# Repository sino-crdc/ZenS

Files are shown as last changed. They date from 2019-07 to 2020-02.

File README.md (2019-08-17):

# ZenS

Multi-function bracelet terminal based on gesture recognition.

手势识别握式手环——多功能终端接口

---
### 目录
- .idea: CLion的一些配置文件以及VCS的配置
- Bracelet Main: 手环主体程序
- Gesture_Detect_Debug: 手势识别的调试程序
- IRrecord: 红外编码收集器
- Model_Physics: 物理模型
- Model_UML: UML模型
- Papers: 项目参考的论文
- Schematic: 原理图(PCB\\电路图\\Datasheet)
- Sotuion: 项目的方案性文件
- CMakeLists.txt: CMakeg构建脚本(暂时没用)
- _config.yml: 项目官网配置

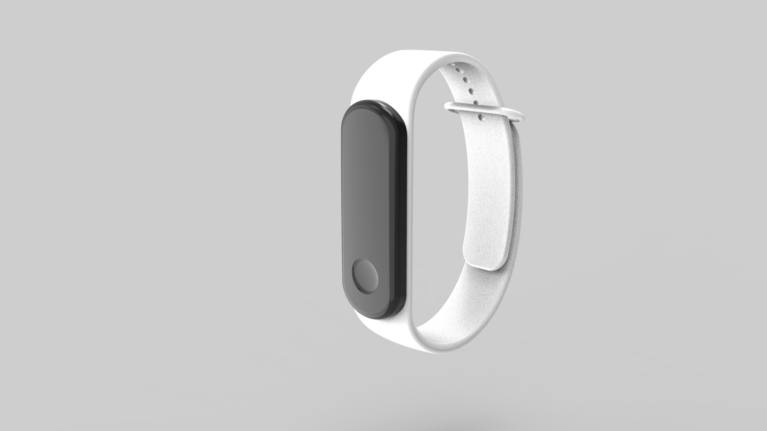
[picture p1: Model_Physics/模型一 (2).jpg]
Notion Image0

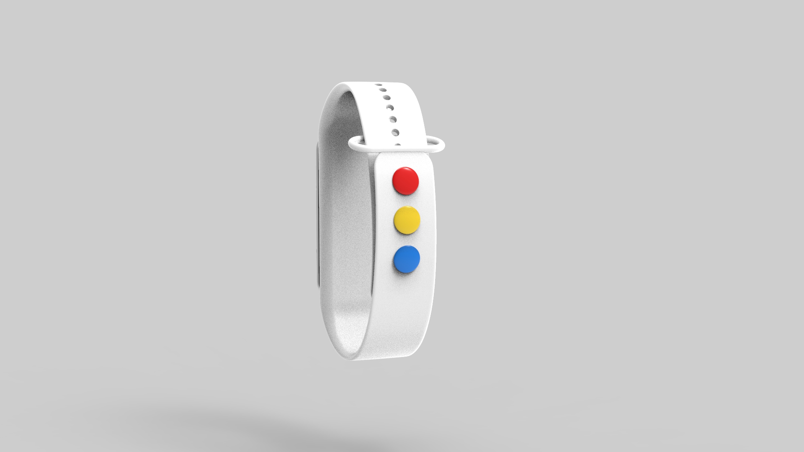
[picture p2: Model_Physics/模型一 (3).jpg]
Notion Image1


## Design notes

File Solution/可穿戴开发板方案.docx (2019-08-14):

# 可穿戴开发板方案

## 需要解决的问题

动态内存(SRAM)问题，时钟问题，大小问题，舒适度问题

## 开发板选择

1. Arduino LilyPad Simple

- 规格：工作电压：3.3V DC 核心控制器：Atmega328V-20PU 外形尺寸:外径50mm,PCB厚度4mm 接口模式；PH2.0
- 具体方案：将LilyPad Simple的PCB原理图修改，取掉不必要的引脚，减小接线片和板空余，印制在硬板或者柔性PCB板上；换芯片为ATmega2560芯片或者Atmel SAM3X8E芯片，芯片引脚与PCB引脚对应连接，剩余芯片引脚不管。芯片兼容性由软件负责人王泽坤、段飞宇和硬件负责人高崇涵、赵宇轩共同完成。

2. Arduino Mega Pro

· 规格：厚度 4mm

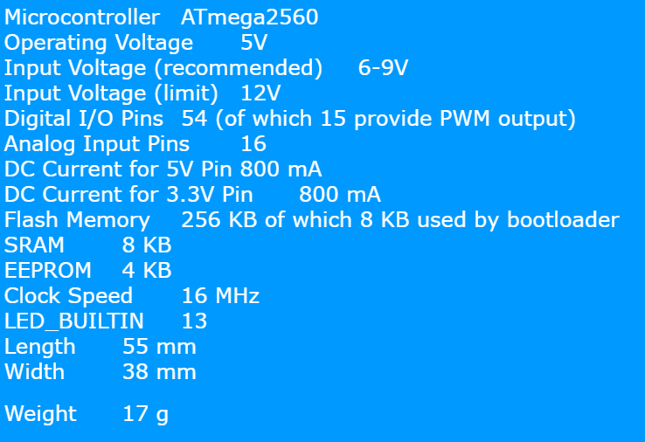
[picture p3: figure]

- 具体方案：可以原封不动，无需修改；也可以修改，将其PCB图去掉不需要的引脚，减小接线片和板材大小，印制在硬的或者柔性PCB板上；更进一步的修改：将芯片ATmega2560换成Atmel SAM3X8E

3. Arduino TinyLily或者TinyDuino

- · 规格：
- TinyDuino: Arduino和LilyPad兼容，可以使用专门的TinyShield扩展板扩展功能，可选的电池托盘（CR16120-CR1632），0.1”间隔的接口用来扩展外部电源，小尺寸和重量（比米国25分币更小），20个IO口（14个数字和6个模拟）-支持所有的Arduino接口！，预置Arduino Bootloader，已经准备好相当数量的堆砌器件
- TinyPad : Arduino LilyPad兼容,可以洗,可以缝超小尺寸（14毫米直径，高度2.8毫米）AtMel328P的cpu 8个IO口，4模拟，4数字 预置Arduino Bootloader USB扩展头
- · 不需要更改PCB，但可能需要印制空板(即不带芯片)
- 芯片均为ATmega328P芯片, 可以牺牲一部分软件稳定性和效率，将全局变量存在Flash当中避免芯片的更换
- · 如果不想牺牲程序效率，那么更换芯片为ATmega2560或者Atmel SAM3X8E
- · 或者仍然采用ATmega328P芯片，但是要多个开发板(或者叫开发小片片)分布式编程，这可能对编码要求比较高，并且芯片的时钟数可能仍然是限制。

4. 改用Nano\Micro\Mini\Leonardo Mini等，均需要换芯片，可改PCB

5. 其他开源开发板Flora\Gemma\Trinket等，均需要换芯片，可改PCB

6. 改用STM32或者ESP8266

7. 改用MCS51单片机

## 动态内存(SRAM)问题

造成内存问题主要是Device中的三个数组，总共占用空间峰值为300KB（最多命令数KB）

1. 减少最多命令数量到50，但是仍然需要扩充动态内存到50KB以上(50-70)

2. 更换芯片，ATmega2560仅有8K还是不够大，应该换成Atmel SAM3X8E

~~3.~~ ~~只更换A~~~~Tmega2560~~~~中的S~~~~RAM~~

4. 将三个数组存储在ROM中(ROM最大空间为300KB), 但是只读

5. 外接RAM

6. 牺牲运行速度，删除三个数组，或者将其换为文件存在SD卡中

7. 将三个数组换为文件存在SD卡中，并提供相邻指令加载算法，即发送B命令编码时候，加载A和C的编码并存在小数组中(一元算法)，根据转动角速度阈值，给出算法的元数(即所加载的相邻指令的数量)

7. 分布式开发板

## 时钟问题

1. 更改芯片内部晶振或更改芯片

2. 换外部时钟

3. 更换单片机开发板

## 大小问题

1. 更改可穿戴开发板方案

2. 更改模式，采用手环+手机或者手环+外部固定单片机或者手环+外部动态单片机或者手环+计算机的模式

## 舒适度问题

1. 更改外壳材料

2. 采用柔性PCB

3. 人体工学

*焊接：更换芯片时候会用到SMT表面组装技术

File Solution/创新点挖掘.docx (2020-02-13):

# 创新点挖掘

定位：终端接口API → 二次开发 → 新型交互方式 → 多样应用场景

1. VR/AR交互

2. 汽车交互

3. PPT交互

4. 设备交互

5. 家居交互

6. 聋哑人群智能家居方式

7. 游戏终端

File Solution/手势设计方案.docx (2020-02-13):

# 手势设计方案

手势通过两种途径与操作关联：运动关联以及图形关联

1. 用户通过电脑设置：需SD卡插入电脑
A. SD卡文件编辑或者桌面应用端，用户通过输入手势表达式或者角度表达式为不同设备不同操作设定手势
B. 在桌面应用端，用户为不同的设备不同的操作选择系统已经提供的手势。
C. 在桌面应用端，用户开启电脑前置摄像头，通过计算机视觉识别用户所作手势，对所选设备和操作设定手势
D. 针对手势识别的train_class方案，结合C
2. 用户通过手环设置：
A. （需要电脑，需SD卡插入电脑，需红外接收器插入电脑）用户用手环做出手势，将手势信息(表达式)通过红外发射到接收器，接收器连接电脑并将数据传到桌面应用端，从而结合方案1设定手势

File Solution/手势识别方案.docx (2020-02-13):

# 手势识别方案

1. 三维霍尔效应传感器
2. 加速度传感器/陀螺仪/角速度计
3. 三个位移传感器
4. 三个测距传感器
5. 三维位置传感器
6. PSD位置传感器

最终确定为方案2，并作如下设置：

定性手势是指不含数值操控的命令手势，比如打开空调、打开空调摆风等。

定量手势是指数值操控的命令手势，比如调整电视音量，调温等。

定量启动手势是指标识定量类型手势的手势，在定量手势之前，是半定性手势半定量手势。

两种手势的区分是：在.infos表中，定量和半定量手势的orderType的开头加一个前缀“$”

手势指令(Gest_Data)：

1. 定性：x+x-分别为x轴正向负向，y+y-为y轴，z+z-为z轴；表达式为”0+1-2+”等
2. 定量：(initial, 180+initial)->(最小值，最大值)，x轴角度，含x轴角速度测量，太大不作用。表达式数值保留一位小数，表达式为“3.8~10.6”等，在角度最大值180°上，考虑到范围超出(抖动或者积分延续)的情况，在表达式中设置18°的误差(“169.0~198.0”):在角度最小值0°上，考虑到抖动至负值的情况，在表达式中设置10°的误差.
3. 半定量：要求最终手部的姿势为胸前平端拳(手心朝下)

手势开发点：

1. 角速度的利用
2. 加速度与角度变化配合：轨迹识别初步
3. 加速度图像识别与积分(图像)识别与双积分：轨迹识别过渡
4. 加速度积分与角度的配合：轨迹识别
5. 其他手势识别方案的尝试与应用

由于JY61芯片MPU6050的固有问题，传送数据的误差较大，数据错乱难以解决，所以更换为LSM9DS0芯片上的加计陀仪。

在方案2中，细分为如下方案：
1. read_process(即读即理): 每读取一包数据立马传到手势检测函数中生成手势表达式或者角度表达式

2. read_store(即读即存)：每读取一包数据，先按照类别存到EEPROM后者SD卡中，之后在手势检测函数中生成手势表达式或者角度表达式

3. train_class(训练分类)：将所有数据读取并上传至电脑，经过与深度学习持久化模型的比对生成手势表达式或者角度表达式(甚至轨迹表达式)传回手环

4. hardport_read(硬串口读取)

定量手势使用read_process方案或者hardport_read方案

定性手势使用四种方案中的一种

定量手势选择为hardport_read方案

定性手势待定

定性手势碰到三个噪音问题，一个自由度问题，一个抓取问题

1. 低阈噪音：将阈值设低容易误读，将阈值设高手势力度要求高
2. 错轴噪音：一轴运动多轴数据
3. 眩晕噪音：多次测量后，加计识别不稳定，需要停歇
4. 轨迹自由度：目前手势轨迹限制为“六向不重复”类型
5. 蒙特卡罗抓取：数据的抓取带有时间随机性，可能在运动时，运动过快(本质是抓取过慢)导致运动时没有加速度数据被抓取，除非正好在运动的时间内抓取到数据。(导致两个问题：一个是不得不让用户重复动作以获取标准手势，另一个是不得不使用simplify函数将一个运动路径单位中抓取的多个数据输出的手势表达式项去重，手势轨迹限制为“不重复”类型)

解决办法：

1. A. 在原有程序中设高阈值，可解决部分错轴噪音。

B. 机器学习办法

2. 一次只读取一轴数据，在原有程序中，判断三轴数值变化幅度，取幅度最大者为阳性，可解决阴性轴上的低阈噪音。
3. 检测眩晕，眩晕时托起程序并显示信号
4. 突破六向限制使用机器学习方法，突破不重复限制需先解决蒙特卡罗抓取问题
5. 加快数据读取与处理(如使用read_store方法)，去掉串口信息语句

基于加计陀螺仪的手势识别方案

1. 传统方案：通过加计判断方向，通过角度判断量值
2. 全角度机器学习方案：通过角度判断轨迹和量值
3. 全数据机器学习方案：通过加速度和角度判断轨迹，通过角度判断量值

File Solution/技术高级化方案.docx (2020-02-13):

# 技术高级化方案

1. 板载机器学习：在开发板中，编写简单的机器学习代码，在手环内单机运行
2. 联网深度学习：增加WiFi模块使设备联网，远程提供深度学习服务，通过手势识别的train_class方案，实现多样的手势识别
3. 定向通信握手：不使用四个按钮对应不同设备，而是使用定向握手的办法，即对准设备，按下按钮，定向发射信号定向回传信号完成设备握手后，(任意指向)做出手势进行操作。
4. 去经验化：手环程序中很多值，比如加速度初始值阈值，角速度阈值等等都是根据肉眼观察到的数据经验地设置的。可以使用MATLAB/Simulink或者其他软件或者数学方法得出一个科学客观的值。

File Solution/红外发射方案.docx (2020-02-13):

# 红外发射方案

红外发射存在两个问题，一个是发射方向的问题，必须对准发射；另一个是发射功率的问题，必须近距离发射。考虑红外反射的话，发射方向问题可以看作为发射功率问题

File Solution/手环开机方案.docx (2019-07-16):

# 手环开关机方案

1. 脱磁方案：磁性一方面可以稳定手环在存放盒中的位置，另一方面方便无线充电，再一方面通过磁感应控制继电器开关。

缺点：需要手环内部带于磁性作用的物质。没有锁定。

优点：位置调控精准，恒定不需能源，相对简单。

2. 机械方案：放手环时通过机械传动关闭开关，拿手环时打开。通过锥形定位等力学定位。

缺点：设计复杂，容易损坏，定位不准。没有锁定。

优点：恒定不需要能源，不需额外传感器或磁器件。

3. 人体感应方案：存放盒内放置感应器，感应到人手后通过机械开/关机。

缺点：需要能源，甚至需要开发板。判断也不准。没有锁定。

优点：设计简单，对手环的要求小。

4. 盒内置推压按键方案：插入盒中的四指推动四个推压按键，通过传动开机，等待3秒后，打开锁定以便拿出手环。通过压力传感器判断放还是拿手环。

缺点：传感器众多，需要开发板。设计复杂。需要能源。容易损坏。

优点：有锁定，对手环的要求小。

*锁定：由于拿出手环后1-3秒，需要让手环处在标准姿态下(手的四指朝下，手心向后，手垂直于地面，手环的加速度为0)，以便手环中手势识别程序部分的校准工作：z轴归零和加计校准。

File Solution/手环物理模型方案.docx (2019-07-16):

# 手环物理模型方案

一、 手背全覆盖模型

针对：LilyPad Simple\Flora\Gemma

材料：中密度纤维板(MDF)或者其他硬质塑料，弹性布料

外形：手背部分整体是一个覆盖全手背的圆形，贴近手背皮肤的部分采用人体工学设计(比如不能带棱角硌手)；手心部分要足够窄小薄，可硬可软，同样要符合人体工学(比如手指按下去能方便的按住按钮，四个按钮的相互距离要适中等)。

二、 手背半覆盖模型

针对：Mega Pro\Nano\Micro\Mini\Leonardo Mini\Trinket

材料：中密度纤维板(MDF)或者其他硬质塑料，弹性布料

外形：手背部分整体是一个覆盖贴近指根部关节的那半部分手背的长条，贴近手背皮肤的部分采用人体工学设计(比如不能带棱角硌手)；手心部分要足够窄小薄，可硬可软，同样要符合人体工学(比如手指按下去能方便的按住按钮，四个按钮的相互距离要适中等)。

三、 排列块模型

针对：小块针对TinyLily\TinyDuino，大块针对Nano

材料：中密度纤维板(MDF)或者其他硬质塑料，块连接线用弹性材料

外形：手背部分类似于Myo腕带，一个块放一个元件/开发板，块间用较宽的弹性带连接(电线套细小绝缘套，盘绕嵌在里面)；手心部分使用弹性带，按钮嵌在里面或外露。

四、 夹层带模型

针对：TinyLily\TinyDuino，柔性PCB

材料：上下外层采用松紧带或其他弹性材料/皮革等，中间内层为各元件/开发板/芯片的上下再各加一薄层硬质材料以保护(增强韧性)

外形：类似绷带，手背部分覆盖半手背，手心部分更为窄小。

注：

1. “针对”详见方案文件《可穿戴开发板方案》

2. 尺寸参数：各开发板的尺寸参数在 “Model_Phsics/parameters/《可穿戴开发板方案》“中给出，未给出的需自行查找，各元件(模块)的尺寸参数长宽以图片的形式给出，厚度均为5毫米

3. 元件的位置排布可与开发板分开，也可以热熔胶粘在开发板表面，视模型和电路等而定，但不能过于拥挤混乱，也不能过于分散浪费空间。而且元件位置排布万万不能反人类，比如“四个按钮和四个发光二极管的位置不对应“。

4. 注意外壳开口或透明：红外发射管外露，发光二极管可见，充电接口(母端)外露，电源按钮外露，SD卡可外露(方便用户取出)可不外露。

5. 加计/陀螺仪/角速度计的放置：x轴手指指向，y轴垂直手指指向向大拇指方向，z轴由右手定则垂直手背面向天。即如图所示：

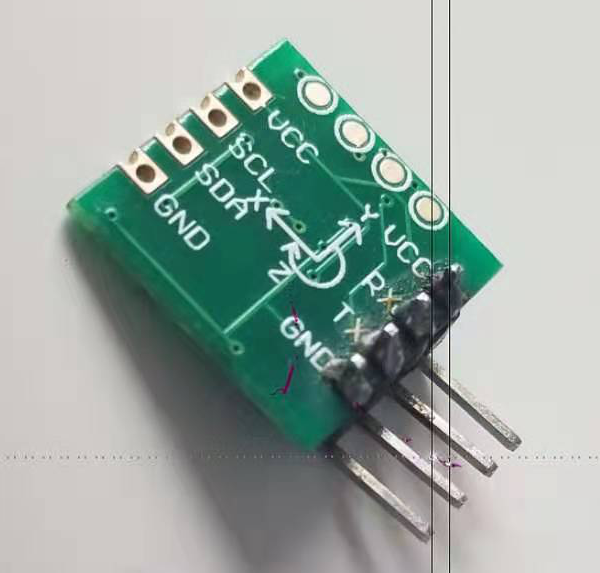
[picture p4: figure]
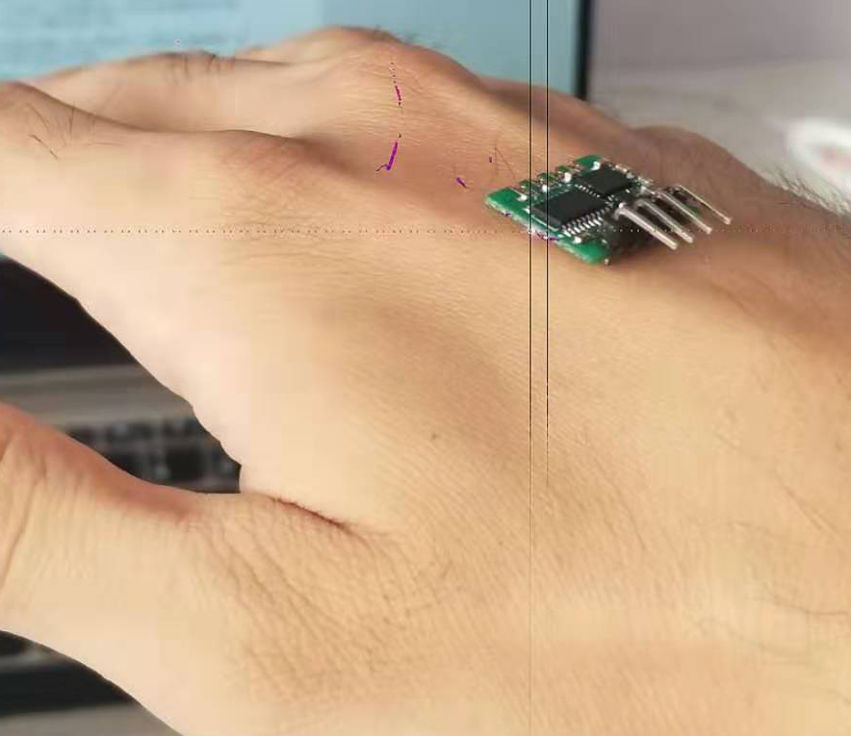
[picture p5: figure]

6. 所有模型均为右手，左手模型日后再议。

7. 从手背走向手心的部分(手侧部分)是决定模型(戴在手上的)稳固性的关键，这部分设计不能太细小窄小，也不能太肥大，要平滑过渡，必要时考虑采用松紧带或者其他弹性材料。

8. 针对STM32\ESP32\MCS51的模型可以是任意的。

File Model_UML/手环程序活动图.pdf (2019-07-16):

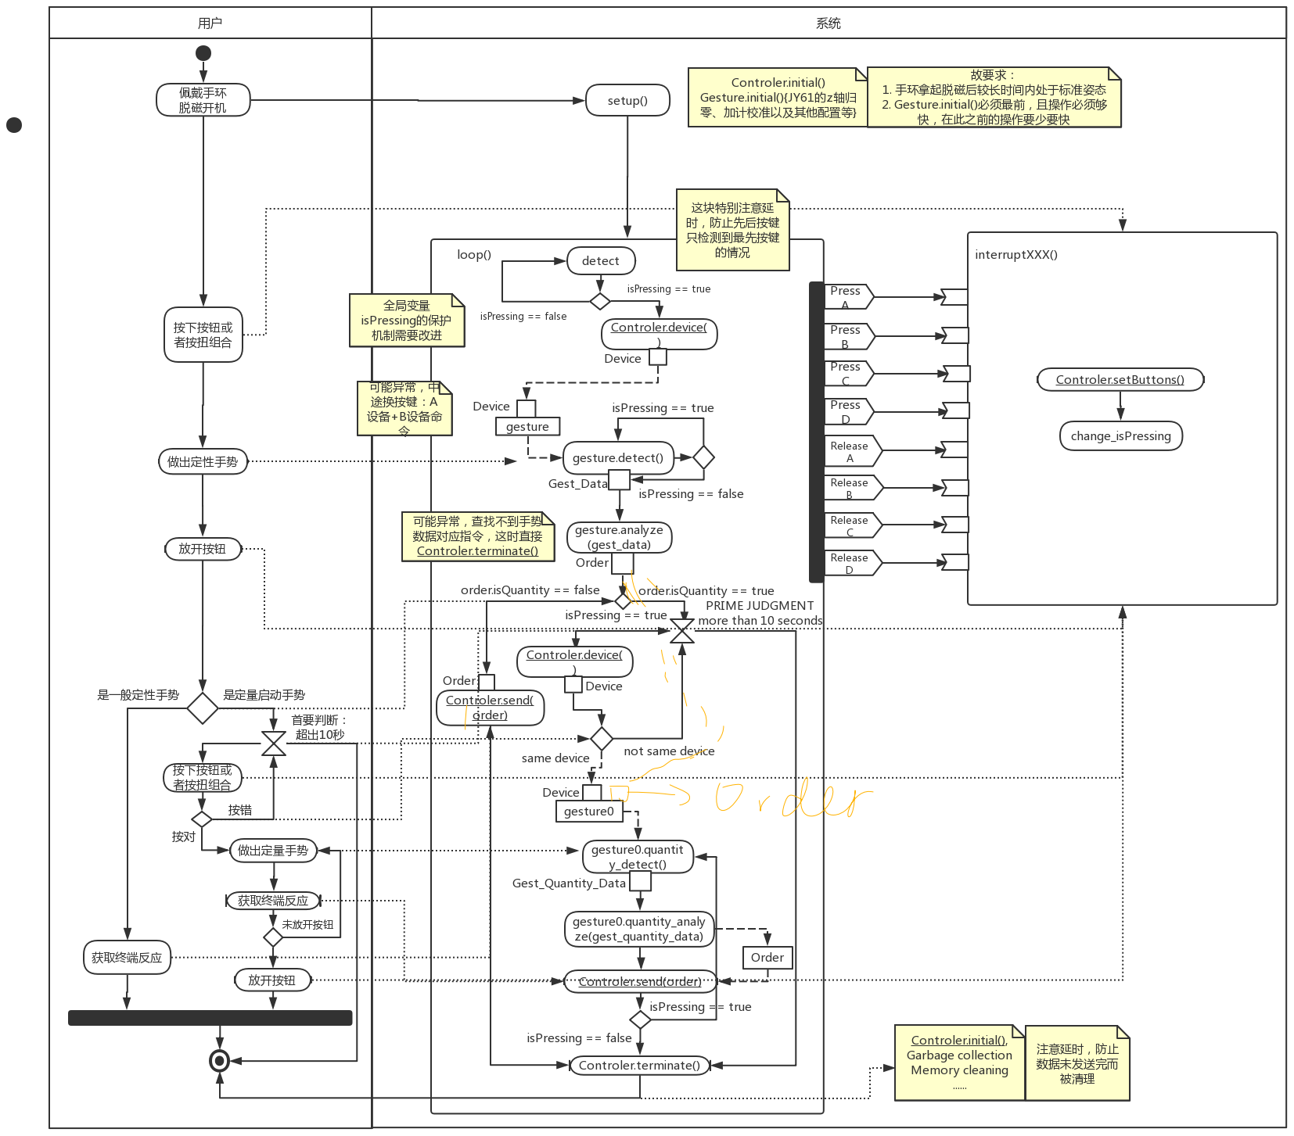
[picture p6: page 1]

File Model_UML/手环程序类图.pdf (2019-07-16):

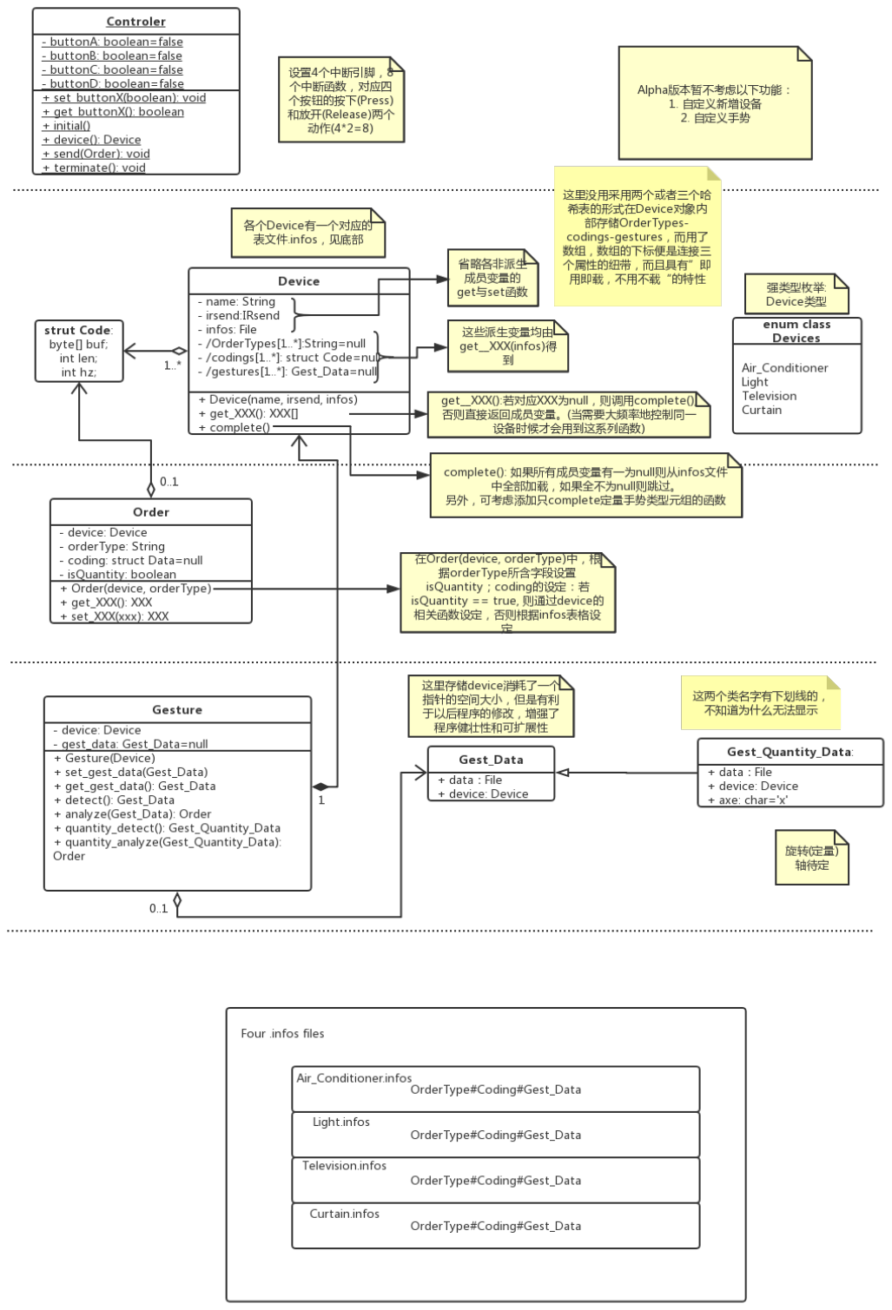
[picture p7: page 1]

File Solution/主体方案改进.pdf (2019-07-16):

# 主体方案改进

方案名称：手握式手环

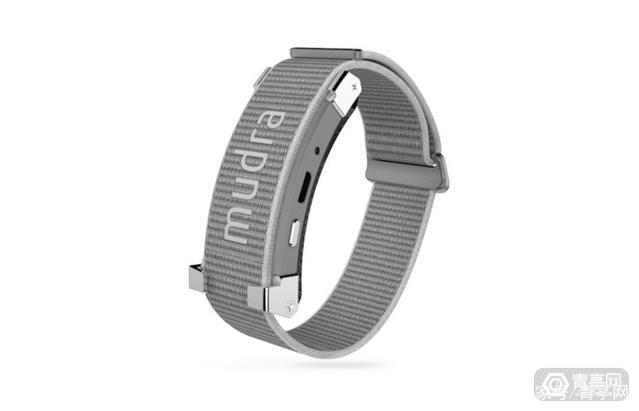
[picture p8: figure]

示例

介绍：类似于半指手套的设计(但是去掉手指部分)。具体地，手环分为两个部分： 手心和手背。手心部分只有简单的四个小按钮 ABCD，用来匹配不同设备，由于手心部 分的元件简单，基本等同于导线，所以不影响用户的生活工作(握笔写字、拿杯子等)； 手背部分则是一些模块或元件：通信模块、CPU、存储器、电池、手势识别模块等。

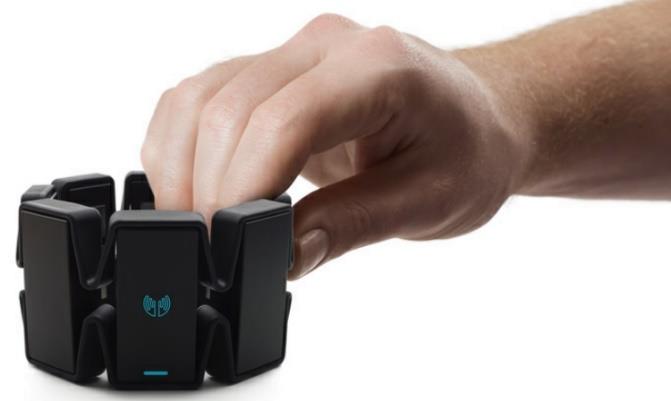
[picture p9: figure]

手背部分模块或元件示例

细节问题：
1. 可控制设备数量限制：设计成轻按和重按两层(类似数码相机的按钮)，或者采取同 时按下多个按钮来扩展可操作设备数的方案(最多可以有 C4

1 + C4

2 + C4

3 + C4
4 种设备)。
2. 本项目可用的手势识别方案：加速度传感器方案、陀螺仪方案、SoundWave（多普 勒效应方案）、GestIC (电场传感方案)等。除了基于以上技术方案的手势识别传感器模块 或芯片外，还有一些可供参考的成品：CMOS 传感器，SOC 芯片 YS4004A 等，以及可供 参考的开源库：Clay SDK, Myo 等（具体可参见相关论文、手册等）。
3. 设备间的连接：蓝牙方案(不建议)，WiFi 方案(建议)，物联网方案(基于 RFID 寻址)， 简单的无线收发模块。
4. 电池：磁吸式充电舱方案(参考无线蓝牙耳机)，USB 充电方案，电池方案(体积大， 不建议)。

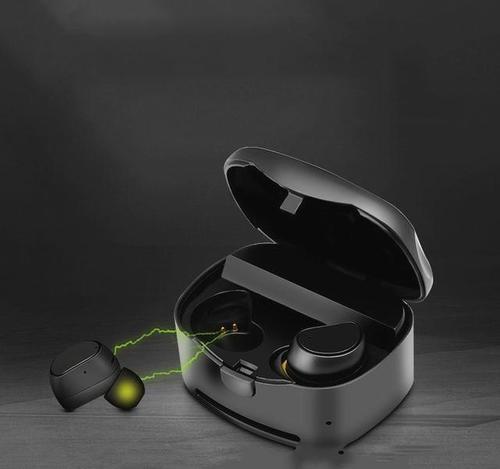
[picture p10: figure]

磁吸式充电舱示例

5. 便携性：设计手环存放盒，实现手环的一秒佩戴一秒摘脱(插手佩戴提手摘)，并把 存放盒作为充电舱。
6. 手心按钮误触：实际生活中，比如握拳、拍击、拧门把手等动作可能误触手心按钮。 可以在食指最底部关节的侧部设置一个总开关按钮，做手势时同时按下总开关与相应手 心按钮即可(这个手部动作并不复杂)。放开总开关时，误触手心按钮不会响应。

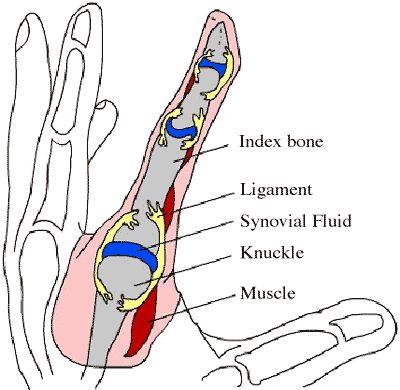
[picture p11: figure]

总开关位置(Synovial Fluid)

7. 舒适性：手心部分由于只有一些简单的按钮和导线，不会给用户带来困扰；手心和 手背的连接使用导线，同样不用担心人性化的问题；手背部分需要注意以下几点：各个 手背模块需要尽可能小，不宽于一指半，以保证手背部分可以足够“柔软”；外壳材料的 选择，贴近皮肤的内层采用软材料，其他外壳部分可采用硬材料；人体工学的应用；甚 至柔性电子(柔性 PCB)的应用。

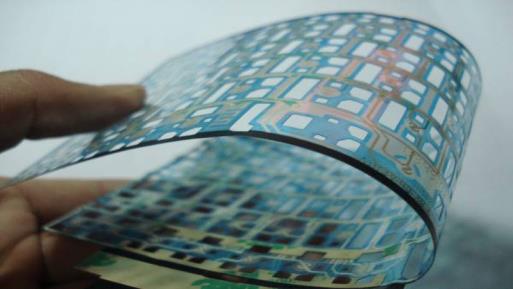
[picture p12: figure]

柔性电子示例

8. 自定义：通过手机或者电脑进行用户的自定义设置，如可以将小指对应的手心按钮 预留为与手机或电脑通信用(或手心按钮全部按下等)，或者采用其他的方案。
9. 防脱落：除了可以调整手环的大小松紧度外，还可以在拇指部位设计一个指套来稳 定手环(一个指套戴得不够牢就在小拇指部位再配一个指套)
10. 手环指示灯甚至小屏幕等。

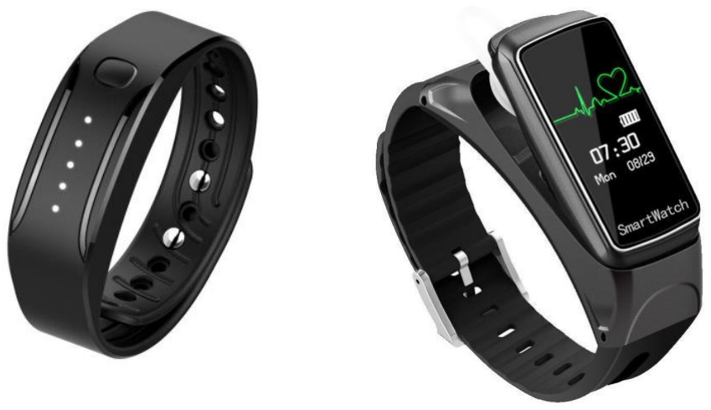
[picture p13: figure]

手环指示灯甚至小屏幕
应用场景:
1. 智能家居场景：进入家门后，把手插进手环存放盒内便迅速佩戴好手环。按住 A 手 心按钮和总开关后，做出相应手势打开空调设置温度甚至定时等；按住 B 手心按钮 和总开关后，做出相应手势打开灯光设置亮度和光色等；按住 C 手心按钮和总开关 后，做出相应手势打开电视设置音量频道和进度条等；按住 D 手心按钮和总开关后， 做出相应手势，控制窗帘开闭等。你可以戴着手环写字、喝水甚至洗脸洗衣(防水设 计)等，日常生活工作基本不受手环影响。入睡前，你将手环插在卧室床头柜的存放 盒里面，手环便自动充电。多么方便的一天啊！

### 2. 介导现实(MR)场景：当你佩戴者 VR 眼镜，看到眼前的虚拟场景，但苦于无法对这

个虚拟现实进行交互。你可以使用我们的手环，不同的手心按钮表示不同的操作种 类，不同的手势表示不同的操作指令，从而构造数字化现实+虚拟数字画面。工业 中，你可以在虚拟现实的指示和与虚拟现实场景的交互中熟练地进行手工制造或者 加工；教育中，教师可以使用手环进行虚拟演示的诸多操作；游戏中，不同手心按 钮是不同的装备(或动作种类)，手势就是你的游戏动作，这样，我们便给你带来一 个沉浸式的游戏体验！等等。

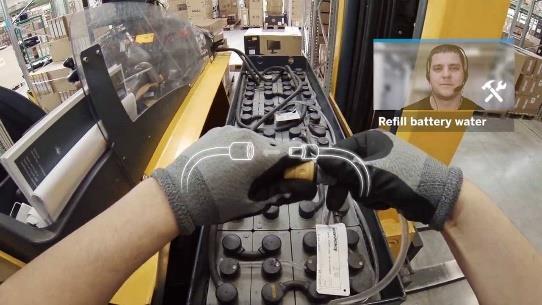
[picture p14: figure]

MR 工业示例(图片是 AR)

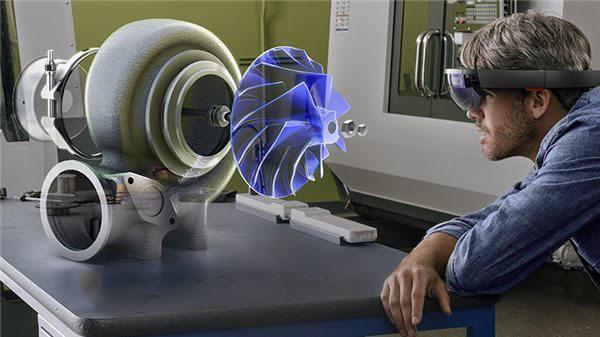
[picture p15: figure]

MR 教育示例(图片是 AR)

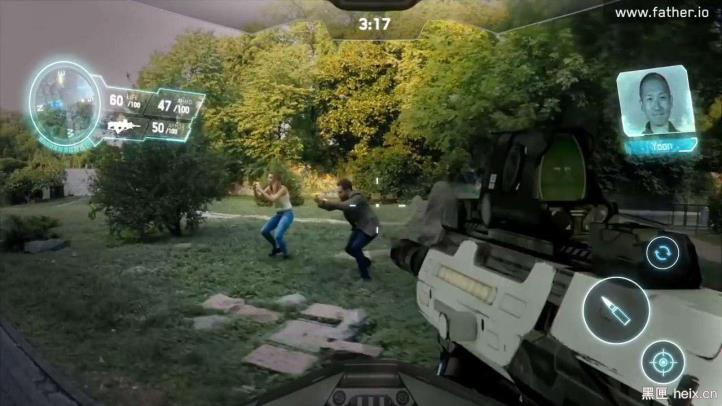
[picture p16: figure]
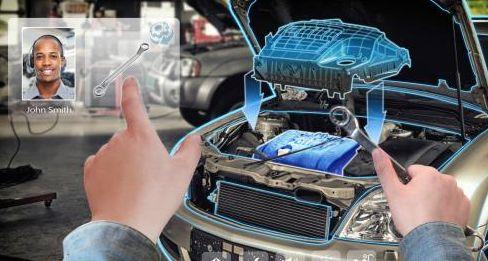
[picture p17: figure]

MR 游戏示例(图片可能是 AR)

3. 其他场景：音乐指挥家可以使用我们的手环进行指挥（增强显示效果）；交通交警可 以通过简单的手势控制红绿灯、街道摄像头等来维护交通；等等。

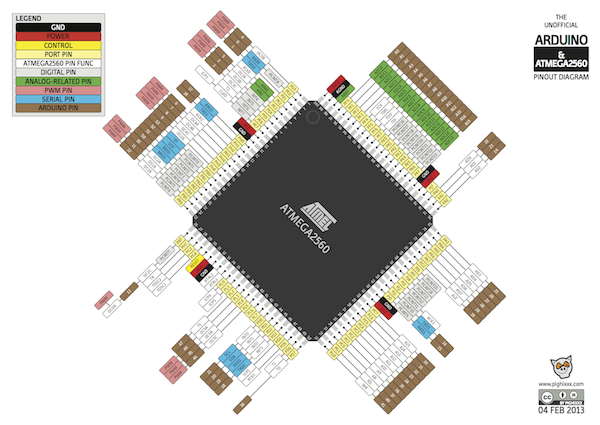
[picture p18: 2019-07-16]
Schematic/Microcontroller/ATmega2560.png

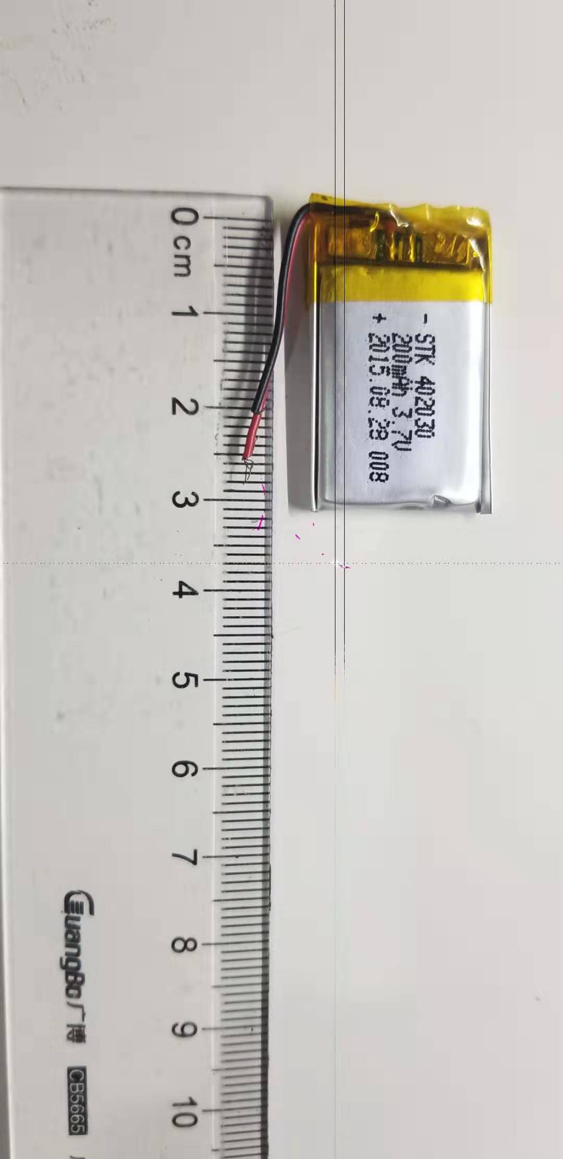
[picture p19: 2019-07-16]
Model_Physics/parameters/电池2.jpg

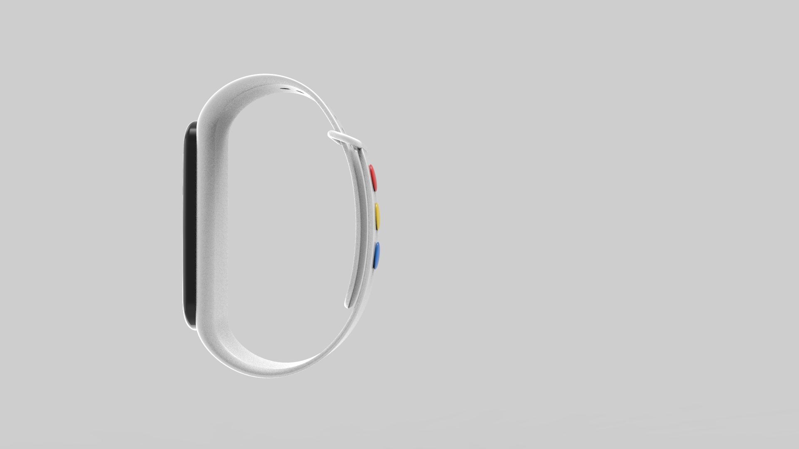
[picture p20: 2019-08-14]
Model_Physics/模型一 (4).jpg

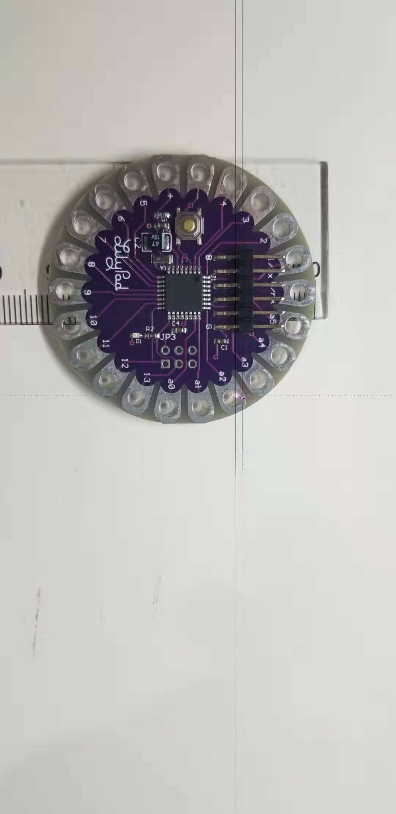
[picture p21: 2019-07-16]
Model_Physics/parameters/LilyPad.jpg

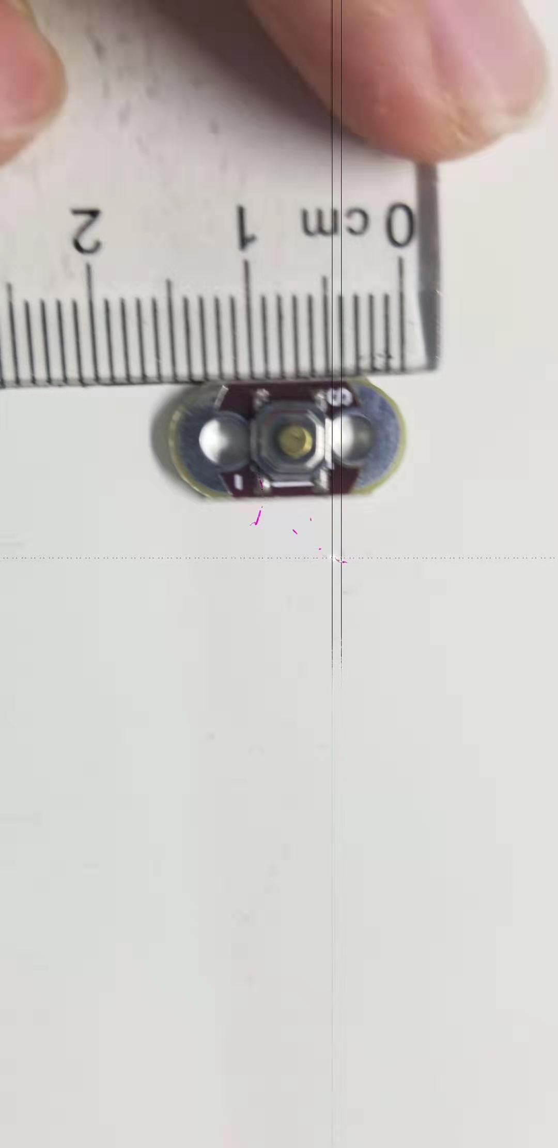
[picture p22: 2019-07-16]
Model_Physics/parameters/手指按键与电源按键.jpg

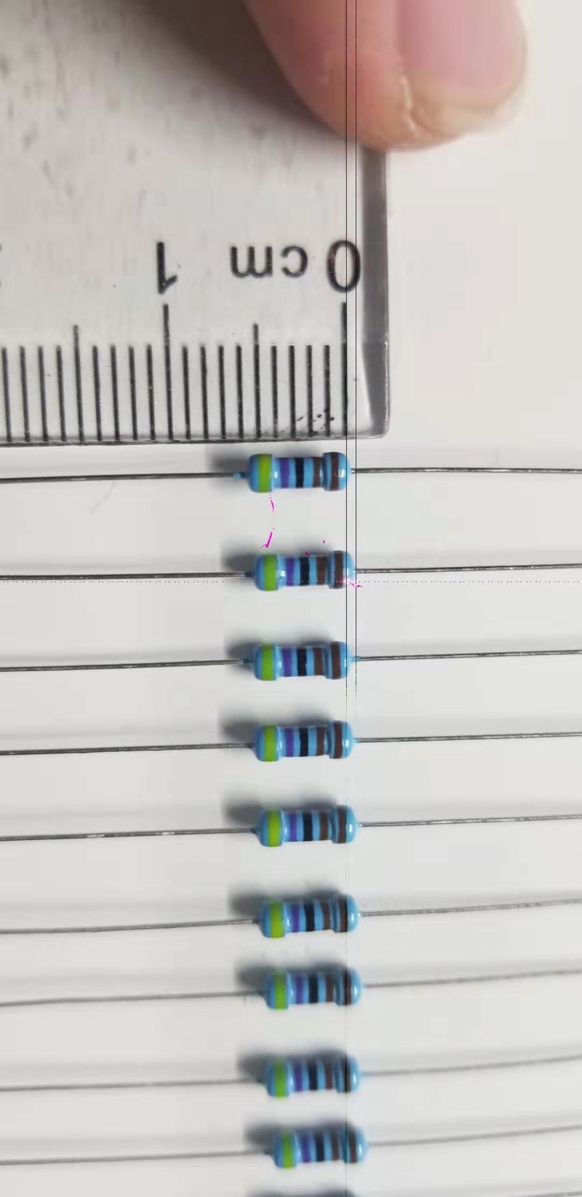
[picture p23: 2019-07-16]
Model_Physics/parameters/电阻2.jpg

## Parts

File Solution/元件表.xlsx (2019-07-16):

ZenS元件表(Arduino Mega2560)(Arduino Mega2560 Pro)
种类 | 数量 | 引脚信息(省略VCC\GND) |  |  |  | 元件改进拓展 | 改进元件引脚拓展 | 再改进 | 再改进元件引脚拓展
SD卡读写器 | 1 | CS:53 (D) | SCK: 52 | MOSI:51 | MISO:50
红外发射管 | 1 | PWM: 3
电池 | 1 | 接充放电一体化模块BAT\GND |  |  |  | 无线充电用具 | 未知
发光二极管 | 4 | D: 46 | D:47 | D: 48 | D: 49
加计\陀螺仪\角速度计 | 1 | RX:9 | TX:10
手指按键 | 4 | D:29 | D:30 | D:31 | D:32 | 电容按键 | GND,VCC,OUT*4
电源按钮 | 1 | 接充放电一体化模块KEY\GND
电阻 | 若干
充放电一体化模块 | 1 | BAT:电池正极 | VIN: 充电线正极 | VOUT: VCC | KEY: 按钮-GND
 |  |  |  |  |  | 蓝牙模块 | TX,RX,VCC,GND,(STAT,PWRC)
 |  |  |  |  |  | LED屏 | VSS,VDD,V0,RS,R\W(GND),E,D*8,A,K | 电容屏 | 未知

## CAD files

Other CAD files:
Model_Physics/物理模型.3dm

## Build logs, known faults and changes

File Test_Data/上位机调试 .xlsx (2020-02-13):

action description | ideal eqation | equation0 | equation1 | equation2 | equation3 | equation4 | baud
左->右(反复) | z+z- | z+z- | z+z- | z+z- |  |  | 9600
上->下(反复) | y-y+
前->后(反复) | x+x-
左->右 | z+z- | x-y+z+z- | z+ | y+z+
 |  |  |  | 结论：很难做到手势精准判断

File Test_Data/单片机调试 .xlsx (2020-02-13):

 | xa | ya | za
20:13:21 | -0.11 | -0.62 | 0.18
20:13:21 | -0.11 | -0.62 | 0.18
20:13:21 | -0.1 | -0.62 | 0.17
20:13:21 | -0.11 | -0.61 | 0.18
20:13:21 | -0.12 | -0.62 | 0.17
20:13:21 | -0.14 | -0.62 | 0.18
20:13:21 | -0.16 | -0.63 | 0.2
20:13:21 | -0.19 | -0.62 | 0.22
20:13:21 | -0.17 | -0.65 | 0.19
20:13:21 | -0.12 | -0.72 | 0.14
20:13:21 | -0.07 | -0.77 | 0.09
20:13:21 | -0.02 | -0.77 | 0.07
20:13:22 | -0.02 | -0.69 | 0.13
20:13:22 | -0.09 | -0.7 | 0.28
20:13:22 | -0.19 | -0.7 | 0.45
20:13:22 | -0.26 | -1.12 | 0.22
20:13:22 | -0.21 | -0.48 | 0.2
20:13:22 | -0.3 | -0.46 | 0.33
20:13:22 | -0.23 | -0.35 | 0.27
20:13:22 | 0 | 0.02 | 0.12
20:13:22 | 0 | 0.25 | 0.09
20:13:22 | -0.06 | 0.29 | 0.13
20:13:22 | -0.14 | 0.23 | 0.17
20:13:22 | -0.21 | -0.03 | 0.18
20:13:22 | -0.2 | -0.13 | 0.15
20:13:22 | -0.18 | -0.56 | -0.06
20:13:22 | -0.44 | -1.39 | 0.06
20:13:22 | -0.31 | -1.63 | -0.16
20:13:22 | -0.41 | -1.47 | -0.1
20:13:22 | -0.58 | -1.01 | 0.13
20:13:22 | -0.54 | -0.78 | 0.16
20:13:22 | -0.16 | 0.25 | 0.24
20:13:22 | -0.32 | -0.68 | 0.01
20:13:22 | -0.36 | -0.87 | 0.01
20:13:22 | -0.41 | -1.03 | 0.02
20:13:22 | -0.41 | -1.19 | 0
20:13:22 | -0.49 | -1.18 | 0.01
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

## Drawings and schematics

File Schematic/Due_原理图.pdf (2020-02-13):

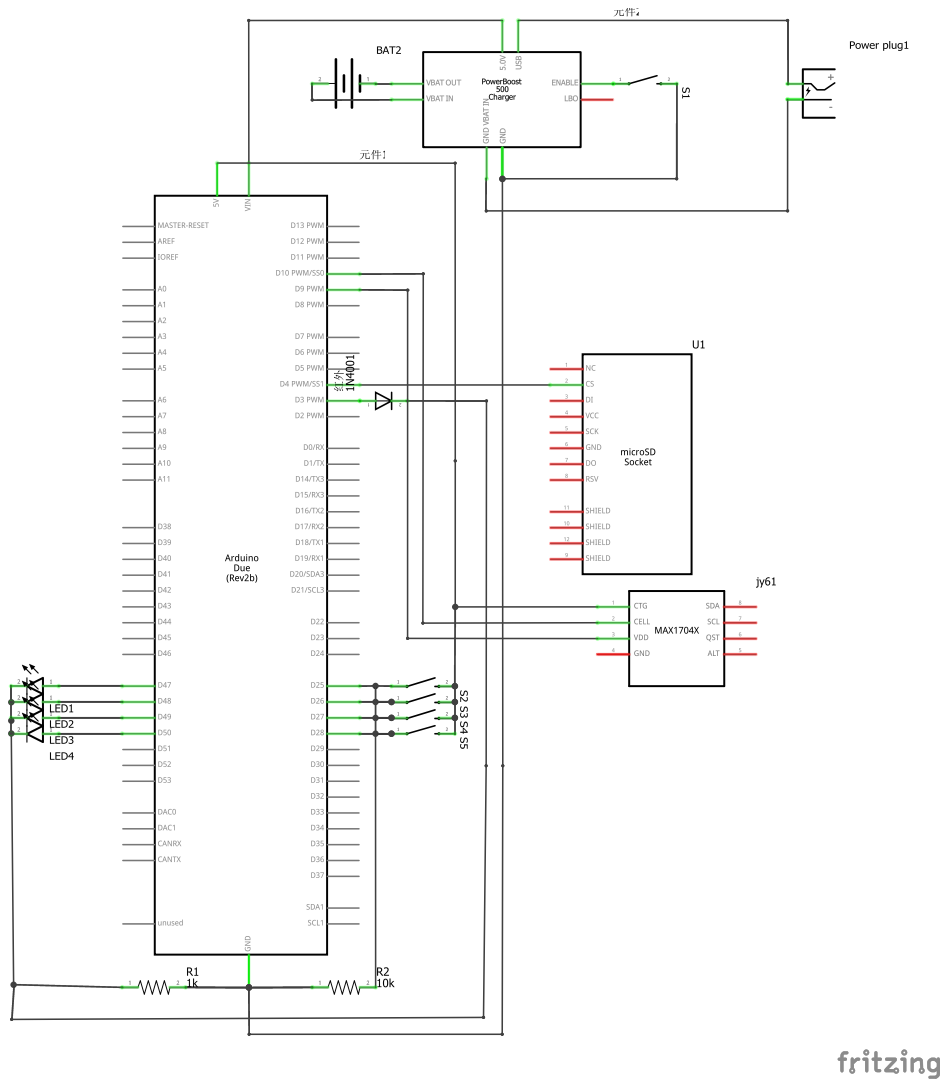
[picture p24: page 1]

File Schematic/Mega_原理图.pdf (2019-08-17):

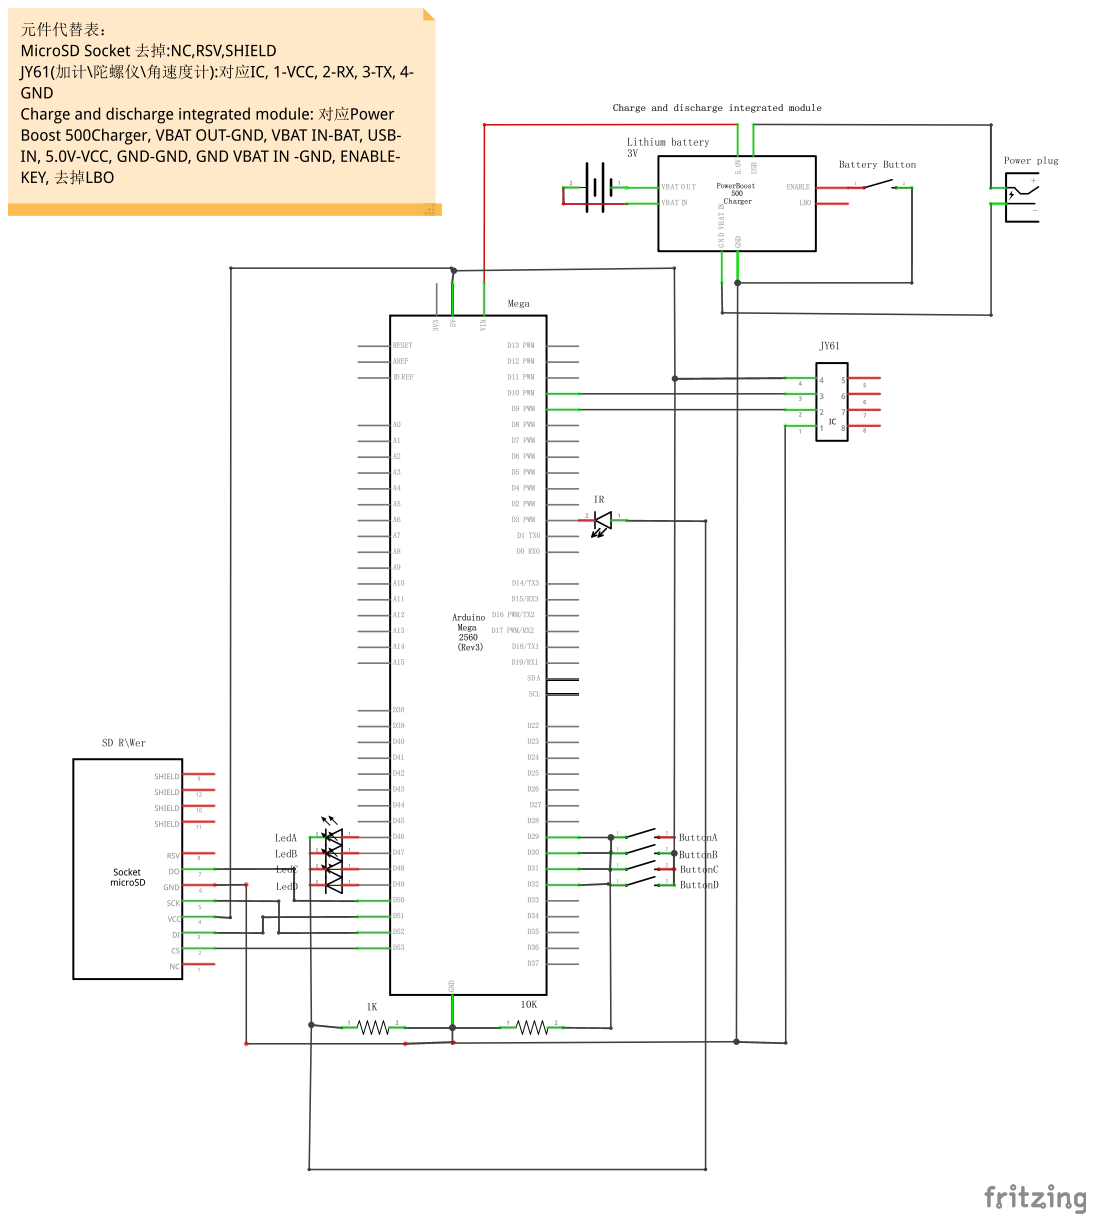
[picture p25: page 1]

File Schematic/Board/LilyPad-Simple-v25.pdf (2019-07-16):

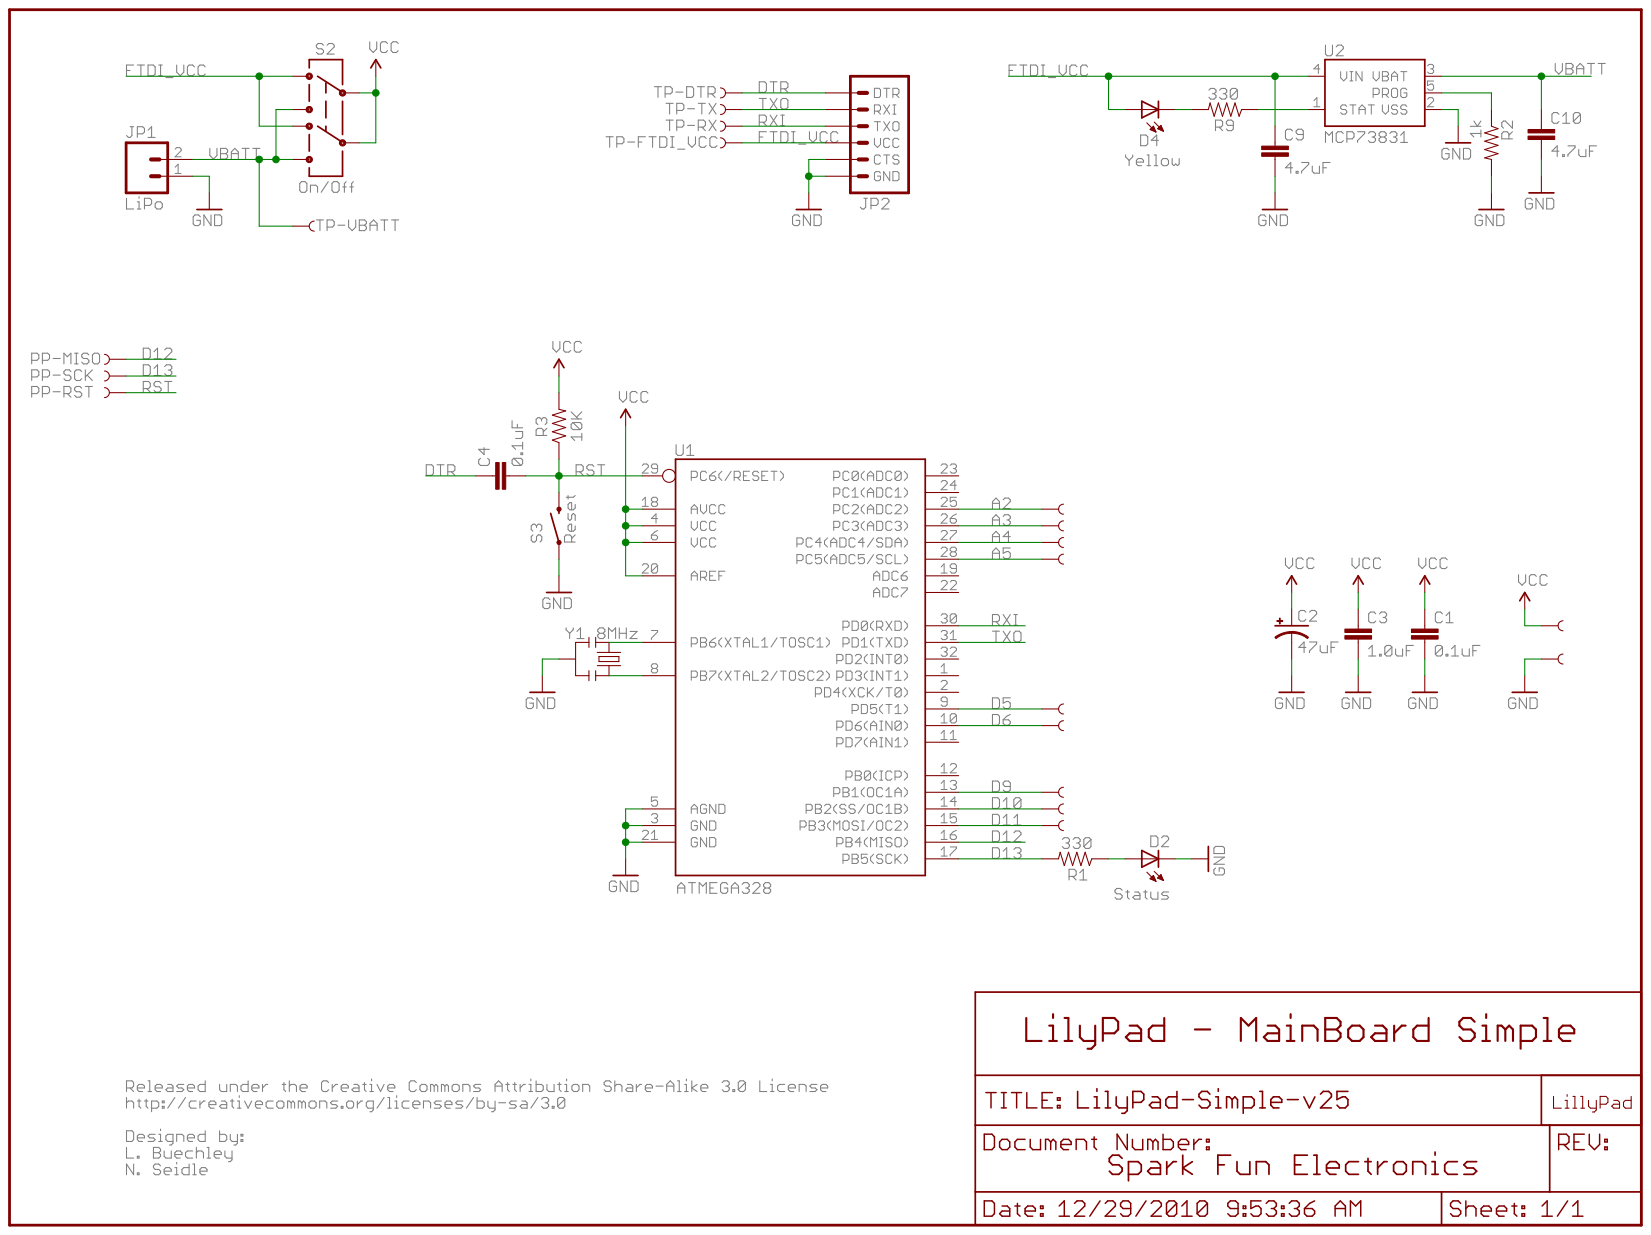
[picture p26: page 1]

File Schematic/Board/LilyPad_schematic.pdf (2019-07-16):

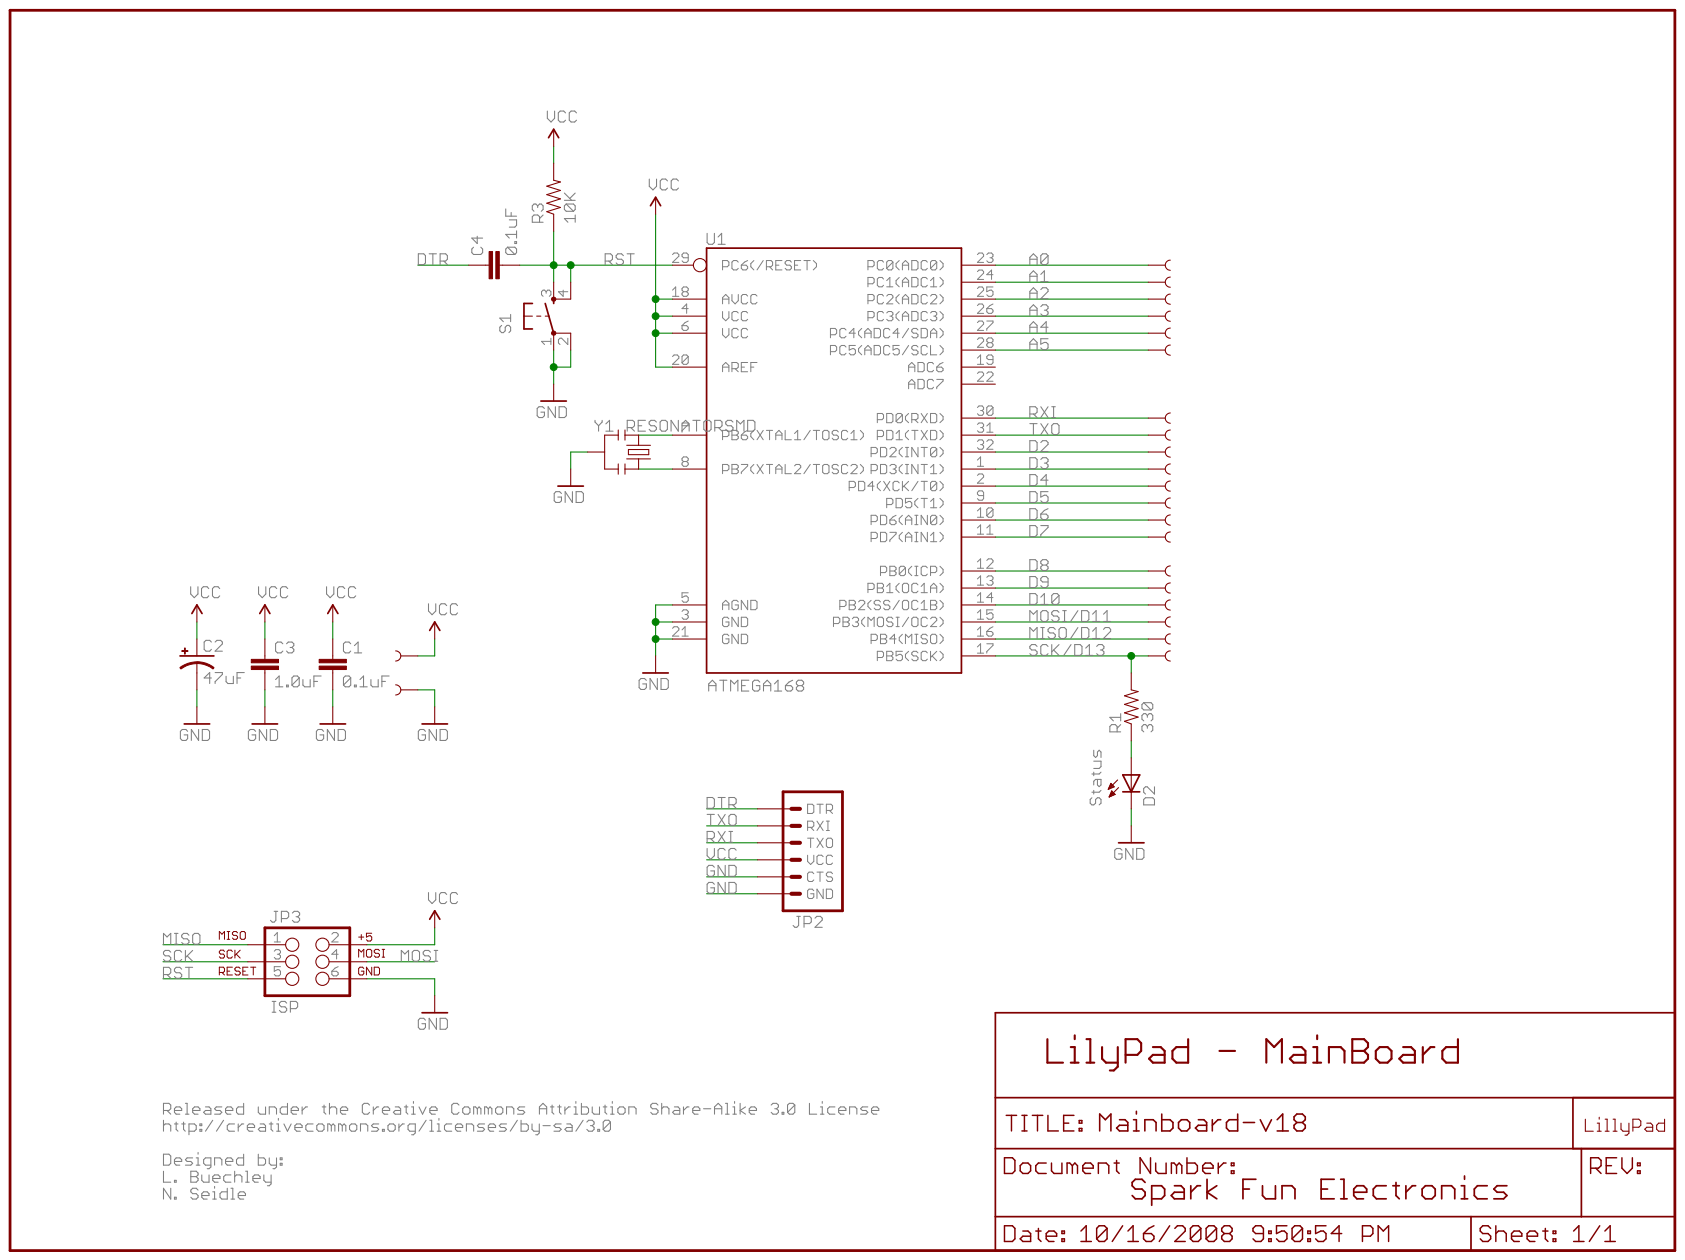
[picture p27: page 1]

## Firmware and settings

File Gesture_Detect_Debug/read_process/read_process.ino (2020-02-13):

/*
   read_process(即读即理):
      每读取一包数据立马传到手势检测函数中生成手势表达式或者角度表达式
*/
#define DAXTHRESHOLD 1.0//x轴加速度可标志临界变化量
#define DAYTHRESHOLD 1.0//y轴加速度可标志临界变化量
#define DAZTHRESHOLD 1.0//z轴加速度可标志临界变化量
#define ABSOLU_XA0 0//x轴绝对初始加速度
#define ABSOLU_YA0 0//y轴绝对初始加速度
#define ABSOLU_ZA0 1//z轴绝对初始加速度
#define ABSOLU_ANGLE0 0.0//初始绝对角度
#define WTHRESHOLD 500.0//角速度最大有效值
#define QUANTITY_AXE 'x'

#define BUTTON 25

static unsigned char Re_buf[11], counter = 0;
static unsigned char sign = 0;
static bool first = true;//用于定性检测函数，是否是第一次传回加速度数据，用来判断以设置加速度初始值
static bool qfirst = true;
static bool cfirst = true;//用于初次校准
static float a[3], w[3], angle[3];

String detect();
void serialEvent();
bool isPressing();
void quantity_detect();
void simplify(String*);

void setup() {
  Serial.begin(4800);
  Serial.println("initializing...");

  Serial1.begin(9600);
  Serial.println("baud rate：115200");

  byte baud[3] = {0xFF, 0xAA, 0x63};
  for (int i = 0; i < 3; i++) {
    Serial1.write(baud[i]);
  }
  Serial.println("baud rate 115200, return rate 100Hz.");
  Serial1.begin(115200);

  byte zzero[3] = {0xFF, 0xAA, 0x52};
  for (int i = 0; i < 3; i++) {
    Serial1.write(zzero[i]);
  } for (int i = 0; i < 3; i++) {
    Serial1.write(zzero[i]);
  }
  Serial.println("z-zeroing");

  byte acheck[3] = {0xFF, 0xAA, 0x67};
  for (int i = 0; i < 3; i++) {
    Serial1.write(acheck[i]);
  } for (int i = 0; i < 3; i++) {
    Serial1.write(acheck[i]);
  }
  Serial.println("A-calibration");

  pinMode(BUTTON, INPUT);
}

void loop() {
  //Serial.println("final equation: " + detect());

  detect();

  //  while(isPressing()){
  //    serialEvent();
  //    Serial.println();
  //  }
}

bool isPressing() {
  return digitalRead(BUTTON) == HIGH;
}

String detect() {
  Serial.println("gesture detecting...");
  String equation = "";
  float xa0 = ABSOLU_XA0;
  float ya0 = ABSOLU_YA0;
  float za0 = ABSOLU_ZA0;
  while (isPressing()) {
    if (cfirst) {
      byte zzero[3] = {0xFF, 0xAA, 0x52};
      for (int i = 0; i < 3; i++) {
        Serial1.write(zzero[i]);
      } for (int i = 0; i < 3; i++) {
        Serial1.write(zzero[i]);
      }
      //    Serial.println("z-zeroing");

      byte acheck[3] = {0xFF, 0xAA, 0x67};
      for (int i = 0; i < 3; i++) {
        Serial1.write(acheck[i]);
      } for (int i = 0; i < 3; i++) {
        Serial1.write(acheck[i]);
      }
      //    Serial.println("A-calibration");

      cfirst = false;
      //delay(2000);
    }
    //获取数据
    serialEvent();
    if (sign) { //若收到数据信号
      //      Serial.println("get sign.");
      sign = 0;
      //解析数据信号
      if (Re_buf[0] == 0x55 && Re_buf [1] == 0x51) { //检查帧头，识别到加速度包
        //        Serial.println("acceleration package gotten.");
        a[0] = (short(Re_buf [3] << 8 | Re_buf [2])) / 32768.0 * 16;//x
        a[1] = (short(Re_buf [5] << 8 | Re_buf [4])) / 32768.0 * 16;//y
        a[2] = (short(Re_buf [7] << 8 | Re_buf [6])) / 32768.0 * 16;//z
      } else if (Re_buf[0] == 0x55 && Re_buf [1] == 0x52) {
        //        Serial.println("angle package gotten");
        continue;
      } else if (Re_buf[0] == 0x55 && Re_buf [1] == 0x53) {
        //        Serial.println("w package gotten");
        continue;
      } else {
        //        Serial.println("I love XiaoKe.");
        continue;
      }

      if (first) { //设置加速度初始值
        //        Serial.println("acceleration initial set.");
        xa0 = a[0];
        //        Serial.print(xa0);
        //        Serial.print(" ");
        ya0 = a[1];
        //        Serial.print(ya0);
        //        Serial.print(" ");
        za0 = a[2];
        //        Serial.print(za0);
        //        Serial.println(" ");
        first = false;
        //Serial.println("xa0: " + String(xa0) + " ya0: " + String(ya0) + " za0: " + String(za0));
        delay(4);
      } else {
        //转换数据信号为手势表达式元素
        String tx = "";
        String ty = "";
        String tz = "";
        if (a[0] - xa0 > DAXTHRESHOLD) {
          //          Serial.print(a[0]-xa0);
          //          Serial.print(" ");
          tx = "x+";
        }
        if (xa0 - a[0] > DAXTHRESHOLD) {
          tx = "x-";
        }
        if (a[1] - ya0 > DAYTHRESHOLD) {
          //          Serial.print(a[1]-ya0);
          //          Serial.print(" ");
          ty = "y+";
        }
        if (ya0 - a[1] > DAYTHRESHOLD) {
          ty = "y-";
        }
        if (a[2] - za0 > DAZTHRESHOLD) {
          //          Serial.print(a[2]-za0);
          //          Serial.print(" ");
          tz = "z+";
        }
        if (za0 - a[2] > DAZTHRESHOLD) {
          tz = "z-";
        }
        equation += tx + ty + tz;
        simplify(&equation);
        //Serial.println(equation);
        Serial.println("xa-xa0: " + String(a[0] - xa0) + " ya-ya0: " + String(a[1] - ya0) + " za-za0: " + String(a[2] - za0));
      }
    }
  }

  first = true;
  cfirst = true;

  return equation;
}

void quantity_detect() {
  Serial.println("quantity gesture detecting...");
  float angle0 = ABSOLU_ANGLE0;
  while (isPressing()) {
    //获取数据
    if (cfirst) {
      byte zzero[3] = {0xFF, 0xAA, 0x52};
      for (int i = 0; i < 3; i++) {
        Serial1.write(zzero[i]);
      } for (int i = 0; i < 3; i++) {
        Serial1.write(zzero[i]);
      }
      //    Serial.println("z-zeroing");

      byte acheck[3] = {0xFF, 0xAA, 0x67};
      for (int i = 0; i < 3; i++) {
        Serial1.write(acheck[i]);
      } for (int i = 0; i < 3; i++) {
        Serial1.write(acheck[i]);
      }
      //    Serial.println("A-calibration");

      cfirst = false;
    }
    serialEvent();
    if (sign) { //若收到数据信号
      //      Serial.println("get sign.");
      sign = 0;
      //解析数据信号
      if (Re_buf[0] == 0x55
          && Re_buf [1] == 0x53) { //检查帧头，识别到角度包
        //        Serial.println("Angle package gotten.");
        angle[QUANTITY_AXE - 120] = (short(Re_buf [(QUANTITY_AXE - 120) * 2 + 3] << 8 | Re_buf [(QUANTITY_AXE - 120) * 2 + 2])) / 32768.0 * 180;
        if (qfirst) { //设置角度初始值
          //          Serial.print("set angle initial:");
          angle0 = angle[QUANTITY_AXE - 120];
          //          Serial.println(angle0);
          qfirst = false;
        }
      }
      //      else if (Re_buf[0] == 0x55
      //                 && Re_buf [1] == 0x52) { //检查帧头，识别到角速度包
      //        Serial.println("w package gotten.");
      //        w[QUANTITY_AXE - 120] = (short(Re_buf [(QUANTITY_AXE - 120) * 2 + 3] << 8 | Re_buf [(QUANTITY_AXE - 120) * 2 + 2])) / 32768.0 * 2000;
      //        //如果角速度太快则挂起程序
      //        if (abs(w[QUANTITY_AXE - 120]) >= WTHRESHOLD) {
      //          Serial.println("w is too fast, hang the program.");
      //          qfirst = true;
      //          continue;
      //        }
      //      }
      else {
        continue;
      }

      //      if (!qfirst && abs(w[QUANTITY_AXE - 120]) < WTHRESHOLD) {
      if (!qfirst) {
        //计算角度偏离量
        //        Serial.println("angle deviation calculating...");
        float deviation = angle[QUANTITY_AXE - 120] - angle0;
        //        deviation = deviation < -10.0 ? 180.0 + deviation : deviation;
        //发送角度
        //        if(deviation<=100.0)
        Serial.println(deviation);
        //Serial.print(" ");
        //      }
      }
    }
  }
  cfirst = true;
  qfirst = true;
}

void serialEvent() {
  unsigned char sum = 0;
  while (Serial1.available()) {
    //char inChar = (char)Serial.read(); Serial.print(inChar); //Output Original Data, use this code
    Re_buf[counter] = (unsigned char)Serial1.read();
    if (counter == 0 && Re_buf[0] != 0x55) continue;//第0号数据不是帧头
    if (counter < 10)
      sum += Re_buf[counter];
    counter++;
    if (counter == 11)          //接收到11个数据
    {
      //      sum &= 0xFF;
      //      Serial.print(sum,DEC);
      //      Serial.print(" ");
      //      Serial.println(Re_buf[counter-1]);
      delay(4);
      if (sum == Re_buf[counter - 1]) {
        //重新赋值，准备下一帧数据的接收
        sign = 1;
      }
      counter = 0;
      break;
    }
    //    Serial.println(sign);
  }
  //  Serial.println("JY61 package reading end.");//这个以及其他一系列的Serail调试信息输出占用很大一块儿时间，对帧传输的灵敏度可能产生影响
}

void simplify(String *s) {
  int len = s->length();
  int * f = (int *)malloc(6 * sizeof(int));
  char * c = (char *)malloc(len * sizeof(char));
  for (int i = 0; i < 6; i++)
    f[i] = 0;
  for (int i = 0; i < len; i++) {
    c[i] = s->charAt(i);
    if (i & 1) {
      int d = (c[i - 1] - 'x') * 2;
      if (c[i] == '-') d++;
      if (f[d])
        c[i - 1] = 0, c[i] = 0;
      else
        f[d] = 1;
    }
  }
  (*s) = "";
  for (int i = 0; i < len; i++) {
    if (c[i])
      s->concat(c[i]);
  }
  free(f);
  free(c);
}

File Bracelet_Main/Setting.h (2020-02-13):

#ifndef Setting_H
#define Setting_H
#if defined(ARDUINO)&&ARDUINO>=100
#include "Arduino.h"
#else
#include "WProgram.h"
#endif
#include <SD.h>

#define AC_ORDER_NUM 50
#define LIGHT_ORDER_NUM 10
#define TELE_ORDER_NUM 200 //这个占用了300KB的动态内存，可以过更改数量为50或者40，如果存在ROM中，减少到250以内(250爆满)
#define CURTAIN_ORDER_NUM 5

#define QUANTITY_AXE 'x'

#define SD_PIN 4

#define RAY_PIN 7

#define BUTTONA_PIN 25
#define BUTTONB_PIN 26
#define BUTTONC_PIN 27
#define BUTTOND_PIN 28

#define GEST_RX_PIN 18
#define GEST_TX_PIN 19


#define LEDA_PIN 47
#define LEDB_PIN 48
#define LEDC_PIN 49
#define LEDD_PIN 50

typedef struct{
  unsigned int buf[243]={0};
  int len = 243;
  int hz = 38;
}Code;//todo: 要不要指针化？
#endif

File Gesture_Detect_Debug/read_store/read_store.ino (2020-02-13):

/**
   read_store(即读即存)：
     每读取一包数据，先按照类别存到EEPROM或者SD卡中，之后在手势检测函数中生成手势表达式或者角度表达式
*/

#include <SoftwareSerial.h>
#include <SD.h>

#define DAXTHRESHOLD 0.5//x轴加速度可标志临界变化量
#define DAYTHRESHOLD 0.5//y轴加速度可标志临界变化量
#define DAZTHRESHOLD 0.5//z轴加速度可标志临界变化量
#define ABSOLU_XA0 1//x轴绝对初始加速度
#define ABSOLU_YA0 -1//y轴绝对初始加速度
#define ABSOLU_ZA0 1//z轴绝对初始加速度
#define ABSOLU_ANGLE0 0.0//初始绝对角度
#define WTHRESHOLD 50.0//角速度最大有效值
#define QUANTITY_AXE 'x'

#define SD_PIN 4

#define GEST_RX_PIN 9
#define GEST_TX_PIN 10
#define BUTTON 13

/*
   1. 配置MPU6050
   2. 等待按键
   3. 读取数据，传回数组
   4. 筛选数组
   5. 对应数组存入SD中
   6. 放开按键，完成读取
   7. 分析SD中数据生成表达式
*/

static unsigned char Re_buf[11], counter = 0;
static unsigned char sign = 0;
static bool first = true;//用于定性表达式生成函数，是否是第一个加速度数据，用来判断以设置加速度初始值
static bool qfirst = true;
static bool cfirst = true;//用于初次校准
static float a[3];

static SoftwareSerial sserial = SoftwareSerial(GEST_TX_PIN, GEST_RX_PIN);

File acceleration_signal;

String detect();
void serialEvent();
bool isPressing();
String equation_generate();
void simplify(String*);
void f_clear();

void setup() {
  // put your setup code here, to run once:
  Serial.begin(4800);
  Serial.println("initializing...");

  sserial.begin(9600);
  Serial.println("baud rate：9600");

  byte baud[3] = {0xFF, 0xAA, 0x63};
  for (int i = 0; i < 3; i++) {
    sserial.write(baud[i]);
  }
  Serial.println("baud rate 115200, return rate 100Hz.");
  sserial.begin(115200);

  byte zzero[3] = {0xFF, 0xAA, 0x52};
  for (int i = 0; i < 3; i++) {
    sserial.write(zzero[i]);
  } for (int i = 0; i < 3; i++) {
    sserial.write(zzero[i]);
  }
  Serial.println("z-zeroing");

  byte acheck[3] = {0xFF, 0xAA, 0x67};
  for (int i = 0; i < 3; i++) {
    sserial.write(acheck[i]);
  } for (int i = 0; i < 3; i++) {
    sserial.write(acheck[i]);
  }
  Serial.println("A-calibration");

  pinMode(BUTTON, INPUT);
  pinMode(SD_PIN, OUTPUT);//  todo
  SD.begin(4);
}

void loop() {
  // put your main code here, to run repeatedly:

  acceleration_signal = SD.open("asignal.txt", FILE_WRITE);
  if (acceleration_signal) {
    if (f_clear()) {
      detect();
    } else {
      Serial.println("Error: file");
      return;
    }
  }
  acceleration_signal.close();
  acceleration_signal = SD.open("asignal.txt", FILE_READ);
  if (acceleration_signal && acceleration_signal.available()) {
    Serial.println(equation_generate());
  }
  acceleration_signal.close();
}

String equation_generate() {
  String equation = "";
  while (acceleration_signal.available()) {
    unsigned char signals[11] = {0};
    for (byte i = 0; i < 11; i++) {
      signals[i] = acceleration_signal.read();
    }

    if (signals[0] == 0x55 && signals [1] == 0x51) {
      a[0] = (short(signals [3] << 8 | signals [2])) / 32768.0 * 16;//x
      a[1] = (short(signals [5] << 8 | signals [4])) / 32768.0 * 16;//y
      a[2] = (short(signals [7] << 8 | signals [6])) / 32768.0 * 16;//z
    }

    float xa0 = ABSOLU_XA0;
    float ya0 = ABSOLU_YA0;
    float za0 = ABSOLU_ZA0;

    if (first) {
      //设置加速度初始值
      xa0 = a[0];
      ya0 = a[1];
      za0 = a[2];

      first = false;
    } else {
      //生成表达式项
      String tx = "";
      String ty = "";
      String tz = "";
      if (a[0] - xa0 > DAXTHRESHOLD) {
        //          Serial.print(a[0]-xa0);
        //          Serial.print(" ");
        tx = "x+";
      }
      if (xa0 - a[0] > DAXTHRESHOLD) {
        tx = "x-";
      }
      if (a[1] - ya0 > DAYTHRESHOLD) {
        //          Serial.print(a[1]-ya0);
        //          Serial.print(" ");
        ty = "y+";
      }
      if (ya0 - a[1] > DAYTHRESHOLD) {
        ty = "y-";
      }
      if (a[2] - za0 > DAZTHRESHOLD) {
        //          Serial.print(a[2]-za0);
        //          Serial.print(" ");
        tz = "z+";
      }
      if (za0 - a[2] > DAZTHRESHOLD) {
        tz = "z-";
      }
      equation += tx + ty + tz;
    }
  }
  return equation;
}

bool isPressing() {
  return digitalRead(BUTTON) == HIGH;
}

bool f_clear() {
  acceleration_signal.close();
  SD.remove(acceleration_signal);
  SD.mkdir("asignal.txt");
  acceleration_signal = SD.open("asignal.txt", FILE_WRITE);
  if (acceleration_signal) {
    return true;
  } else {
    return false;
  }
}

void detect() {
  while (isPressing()) {
    if (cfirst) {
      byte zzero[3] = {0xFF, 0xAA, 0x52};
      for (int i = 0; i < 3; i++) {
        sserial.write(zzero[i]);
      } for (int i = 0; i < 3; i++) {
        sserial.write(zzero[i]);
      }
      //    Serial.println("z-zeroing");

      byte acheck[3] = {0xFF, 0xAA, 0x67};
      for (int i = 0; i < 3; i++) {
        sserial.write(acheck[i]);
      } for (int i = 0; i < 3; i++) {
        sserial.write(acheck[i]);
      }
      //    Serial.println("A-calibration");

      cfirst = false;
    }
    //获取数据
    serialEvent();
    if (sign) { //若收到数据信号
      //      Serial.println("get sign.");
      sign = 0;
      //解析数据信号
      if (Re_buf[0] == 0x55 && Re_buf [1] == 0x51) { //检查帧头，识别到加速度包
        //        Serial.println("acceleration package gotten.");
        for (int i = 0; i < 11; i++) {
          acceleration_signal.write(Re_buf[i]);
        }
      } else {
        //        Serial.println("I love XiaoKe.");
        continue;
      }
    }
  }
}
cfirst = true;
}

void serialEvent() {
  while (sserial.available()) {
    //char inChar = (char)Serial.read(); Serial.print(inChar); //Output Original Data, use this code
    Re_buf[counter] = (unsigned char)sserial.read();
    if (counter == 0 && Re_buf[0] != 0x55) continue; //第0号数据不是帧头
    counter++;
    if (counter == 11)          //接收到11个数据
    {
      counter = 0;             //重新赋值，准备下一帧数据的接收
      sign = 1;
      break;
    }
  }
  //  Serial.println("JY61 package reading end.");//这个以及其他一系列的Serail调试信息输出占用很大一块儿时间，对帧传输的灵敏度可能产生影响
}

void simplify(String *s) {
  int len = s->length();
  int * f = (int *)malloc(6 * sizeof(int));
  char * c = (char *)malloc(len * sizeof(char));
  for (int i = 0; i < 6; i++)
    f[i] = 0;
  for (int i = 0; i < len; i++) {
    c[i] = s->charAt(i);
    if (i & 1) {
      int d = (c[i - 1] - 'x') * 2;
      if (c[i] == '-') d++;
      if (f[d])
        c[i - 1] = 0, c[i] = 0;
      else
        f[d] = 1;
    }
  }
  (*s) = "";
  for (int i = 0; i < len; i++) {
    if (c[i])
      s->concat(c[i]);
  }
  free(f);
  free(c);
}

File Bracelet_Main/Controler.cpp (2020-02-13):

#if ARDUINO>=100
#include "Arduino.h"
#else
#include "WProgram.h"
#endif

#include "Controler.h"

extern Device air_conditioner;
extern Device light;
extern Device television;
extern Device curtain;
IRsend irsend;

Controler::Controler(){}

void Controler::setButtonA(bool state)
{
  buttonA = state;
//  Serial.println("buttonA == " + String(buttonA));
}
void Controler::setButtonB(bool state)
{
  buttonB = state;
//  Serial.println("buttonB == " + String(buttonB));
}
void Controler::setButtonC(bool state)
{
  buttonC = state;
//  Serial.println("buttonC == " + String(buttonC));
}
void Controler::setButtonD(bool state)
{
  buttonD = state;
//  Serial.println("buttonD == " + String(buttonD));
}
bool Controler::getButtonA()
{
  return buttonA;
}
bool Controler::getButtonB()
{
  return buttonB;
}
bool Controler::getButtonC()
{
  return buttonC;
}
bool Controler::getButtonD()
{
  return buttonD;
}
void Controler::initial()
{
  Serial.println("controler initializing...");
  buttonA = false;
  buttonB = false;
  buttonC = false;
  buttonD = false;
  Serial.println("controler initialized.");
}
Device* Controler::device()
{
  Serial.println("device searching...");
  Device* device = NULL;
  Serial.println("device == NULL");
  if (buttonA){
    device = &light;
    Serial.println("device == light");
  }
  else if (buttonB)
    device = &air_conditioner;
  else if (buttonC)
    device = &television;
  else if (buttonD)
    device = &curtain;
  return device;
}
void Controler::send(Order* order)
{
  Serial.println("order sending...");
  if (order != NULL) {
    Serial.print("order sent: ");
    Serial.println("device^"+order->getDevice()->getName() + " ordertype^"+order->getOrderType());
    //Serial.println(order->getCode().buf[0],DEC);
    //Serial.println(order->getCode().hz);
    irsend.sendRaw(order->getCode().buf, order->getCode().len, order->getCode().hz);//可能需要加上循环连环发射密集轰炸
    //delay(2000);
  } else {
    Serial.println("order == NULL");
  }
}
void Controler::terminate()
{
  Serial.println("controler terminating...");
  buttonA = false;
  buttonB = false;
  buttonC = false;
  buttonD = false;
  //todo: C++垃圾回收机制
  Serial.println("controler terminated.");
}
bool Controler::isPressing()
{
  Controler::detect();
  if (buttonA || buttonB || buttonC || buttonD) {
//    Serial.println("pressing.");
    return true;
  }
  else {
//    Serial.println("not pressing.");
    return false;
  }
}
byte Controler::detect() {
//  Serial.println("detecting...");
  if (digitalRead(BUTTONA_PIN) == HIGH) {
    setButtonA(true);
    digitalWrite(LEDA_PIN, HIGH);
//    Serial.println("ledA == HIGH");
    return 1;
  }
  else {
    setButtonA(false);
    digitalWrite(LEDA_PIN, LOW);
  }

  if (digitalRead(BUTTONB_PIN) == HIGH) {
    setButtonB(true);
    digitalWrite(LEDB_PIN, HIGH);
//    Serial.println("ledB == HIGH");
    return 2;
  }
  else{
    setButtonB(false);
    digitalWrite(LEDB_PIN, LOW);
  }

  if (digitalRead(BUTTONC_PIN) == HIGH) {
    setButtonC(true);
    digitalWrite(LEDC_PIN, HIGH);
//    Serial.println("ledC == HIGH");
    return 3;
  }
  else{
    setButtonC(false);
    digitalWrite(LEDC_PIN, LOW);
  }


  if (digitalRead(BUTTOND_PIN) == HIGH) {
    setButtonD(true);
    digitalWrite(LEDD_PIN, HIGH);
//    Serial.println("ledD == HIGH");
    return 4;
  }
  else{
    setButtonD(false);
    digitalWrite(LEDD_PIN, LOW);
  }

  return 0;
}

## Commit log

2019-07-15 With Simon, we have finished the initial version of main program of bracelet.2019.7.13.(without the Circuit schematic)
2019-07-16 The next phase...
    [ATmega2560_Library.SchLib, ZenS.fzz, 元件表.xlsx]
2019-08-02 传入红外线信号收集记录器。
    [ZenS.fzz]
2019-08-02 README条目变更
2019-08-03 更新动态存储机制
2019-08-03 更新动态存储机制,修改了一些变量的存储期
2019-08-09 第二次完全的更新动态内存分配机制 调整了变量作用域和生存期 成功将内存占用降到31%
2019-08-10 更新方案，提出四个问题及其解决方案，并修改设备最大指令数
2019-08-14 上传模型示意
2019-08-14 修改README概念图
2019-08-14 确定阻值
2019-08-16 修改LED灯相关代码
2019-08-16 修改电路图，增加调试代码
    [ZenS.fzz]
2019-08-16 增加测试代码
2019-08-16 本应是master
2019-08-17 全部调试代码和调试后改动
2019-08-17 误删文件重新上传
2019-08-17 修改README.md
2019-08-17 去掉调试代码
2019-08-18 更改了红外接收，增加了红外发射
2019-08-18 手势识别调试与修改
2019-08-18 改动了手势识别的调试代码
2019-08-20 增加了trim
2019-08-20 面向薛定谔程序设计的成功
2019-08-22 手势调试的初步成功，但也发现了简单识别方式的缺陷
2019-08-23 文件信息读取方式的修改
2019-08-24 创新点挖掘-手势新方式
2019-08-25 手势设计方案和红外发射方案
2019-08-25 delay（4）
2019-08-25 delay（4）2号
2019-08-26 技术高级化和数据
    [上位机调试 .xlsx, 单片机调试 .xlsx]
2019-08-26 最佳测试代码_826
2019-08-27 因为校准有延迟，去掉校准
2019-08-27 增加错轴噪音解决办法
2020-02-02 a
    上位机，目前由于设备原因analysis函数未完善
2020-02-02 上位机，由于新买的jy61没到，analysis函数尚未完善
2020-02-04 更新数据预处理三个函数，数据截取暂时用的均分
2020-02-11 用c编写的基于共享内存的进程通信发送端
2020-02-11 用c编写的基于共享内存的进程间通信接收端
2020-02-11 共享内存数据类型定义
2020-02-14 进程间通信_共享内存_c++发送端
2020-02-14 进程间通信_共享内存_python接收端
2020-02-14 被我抛弃了
2020-02-14 更新预处理函数，暂时用均分
2020-02-14 也被我抛弃了
2020-02-14 依然，抛弃
2020-02-16 增加代码可读性
